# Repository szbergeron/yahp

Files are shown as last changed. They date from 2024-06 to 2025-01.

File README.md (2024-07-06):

WARN: Not ready for use yet

The boards are semi-final, but I need to finish part selection and push a new variant that allows varying sensor position.
Code is in Proof-of-Concept state, and has a lot of stuff hard-coded that should be pulled out into configs.

#Because getting an AvantGrand would just be way too easy

Inspired by [Greg Zweigle's DIY Hybrid Piano](https://github.com/gzweigle/DIY-Grand-Digital-Piano) and the [Cybrid Project](https://github.com/ekumanov/cybrid).

I don't come from a hardware/EE background, so a lot of that stuff was done by feel rather than through meticulous science. Instead, I tried to all of the "magic" through software. The sensors are probably not "ideal", but they are cheap and dumb simple. I didn't use trimmers or anything like that to calibrate, opting instead to gather raw measurements and then apply software correction. I also opted to use onboard ADCs instead of external ones or any kind of extra voltage reference. This absolutely introduces some inaccuracy in the lower bits of the raw measurements, but again--software magic :)

The flip side of using such a simple design from an EE perspective is that fabrication is _dumb simple_, even if technically more expensive when looking at the BOM. Each key uses a single sensor, and there is an MCU for every 16 keys, plus some basic power filtering all on a PCB. I'm spectacularly bad at soldering, so this has as little of it as I could get away with. This project is aimed at being an easy "kit" to get components for and assemble. Follow along if you'd like!

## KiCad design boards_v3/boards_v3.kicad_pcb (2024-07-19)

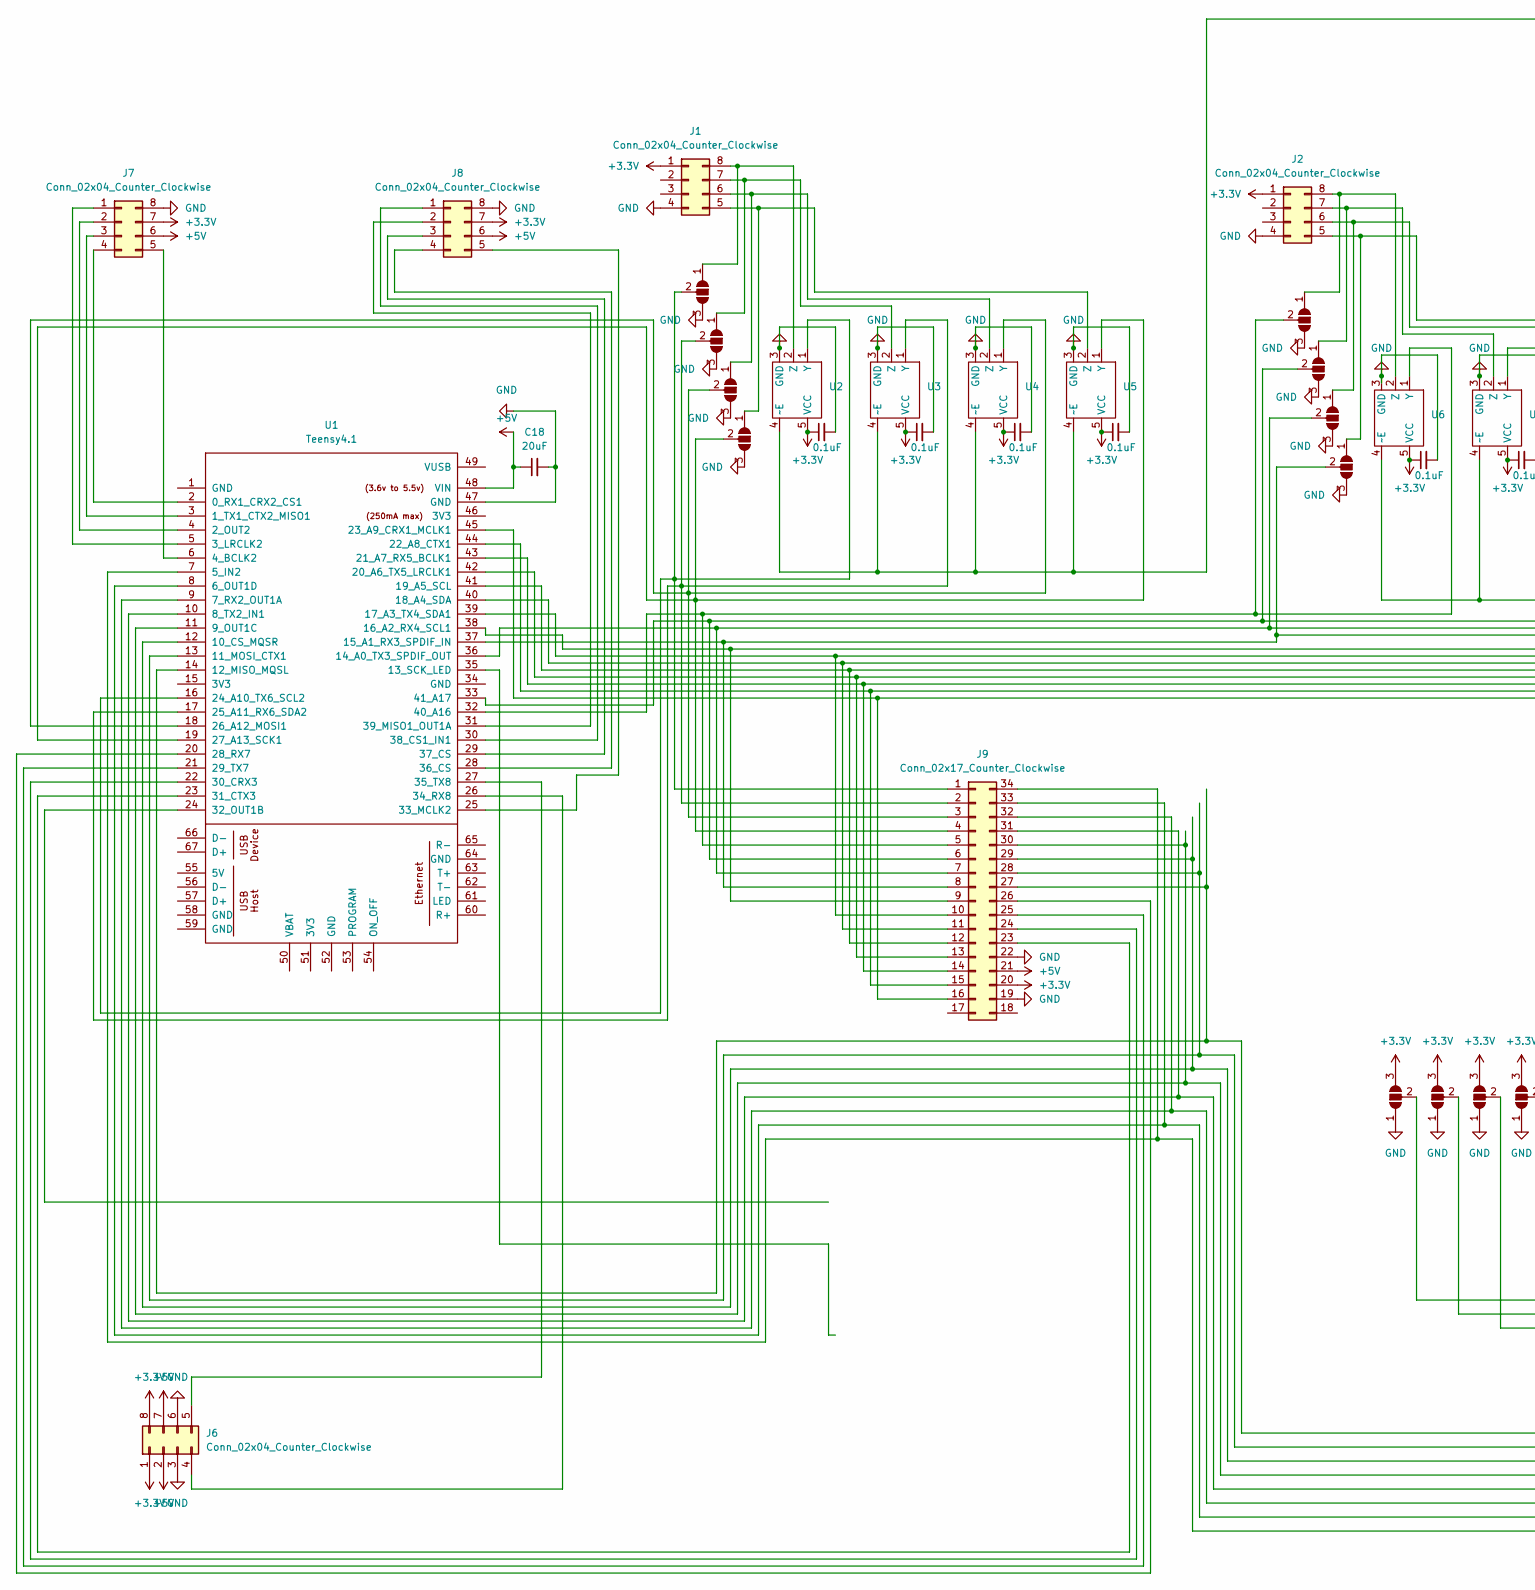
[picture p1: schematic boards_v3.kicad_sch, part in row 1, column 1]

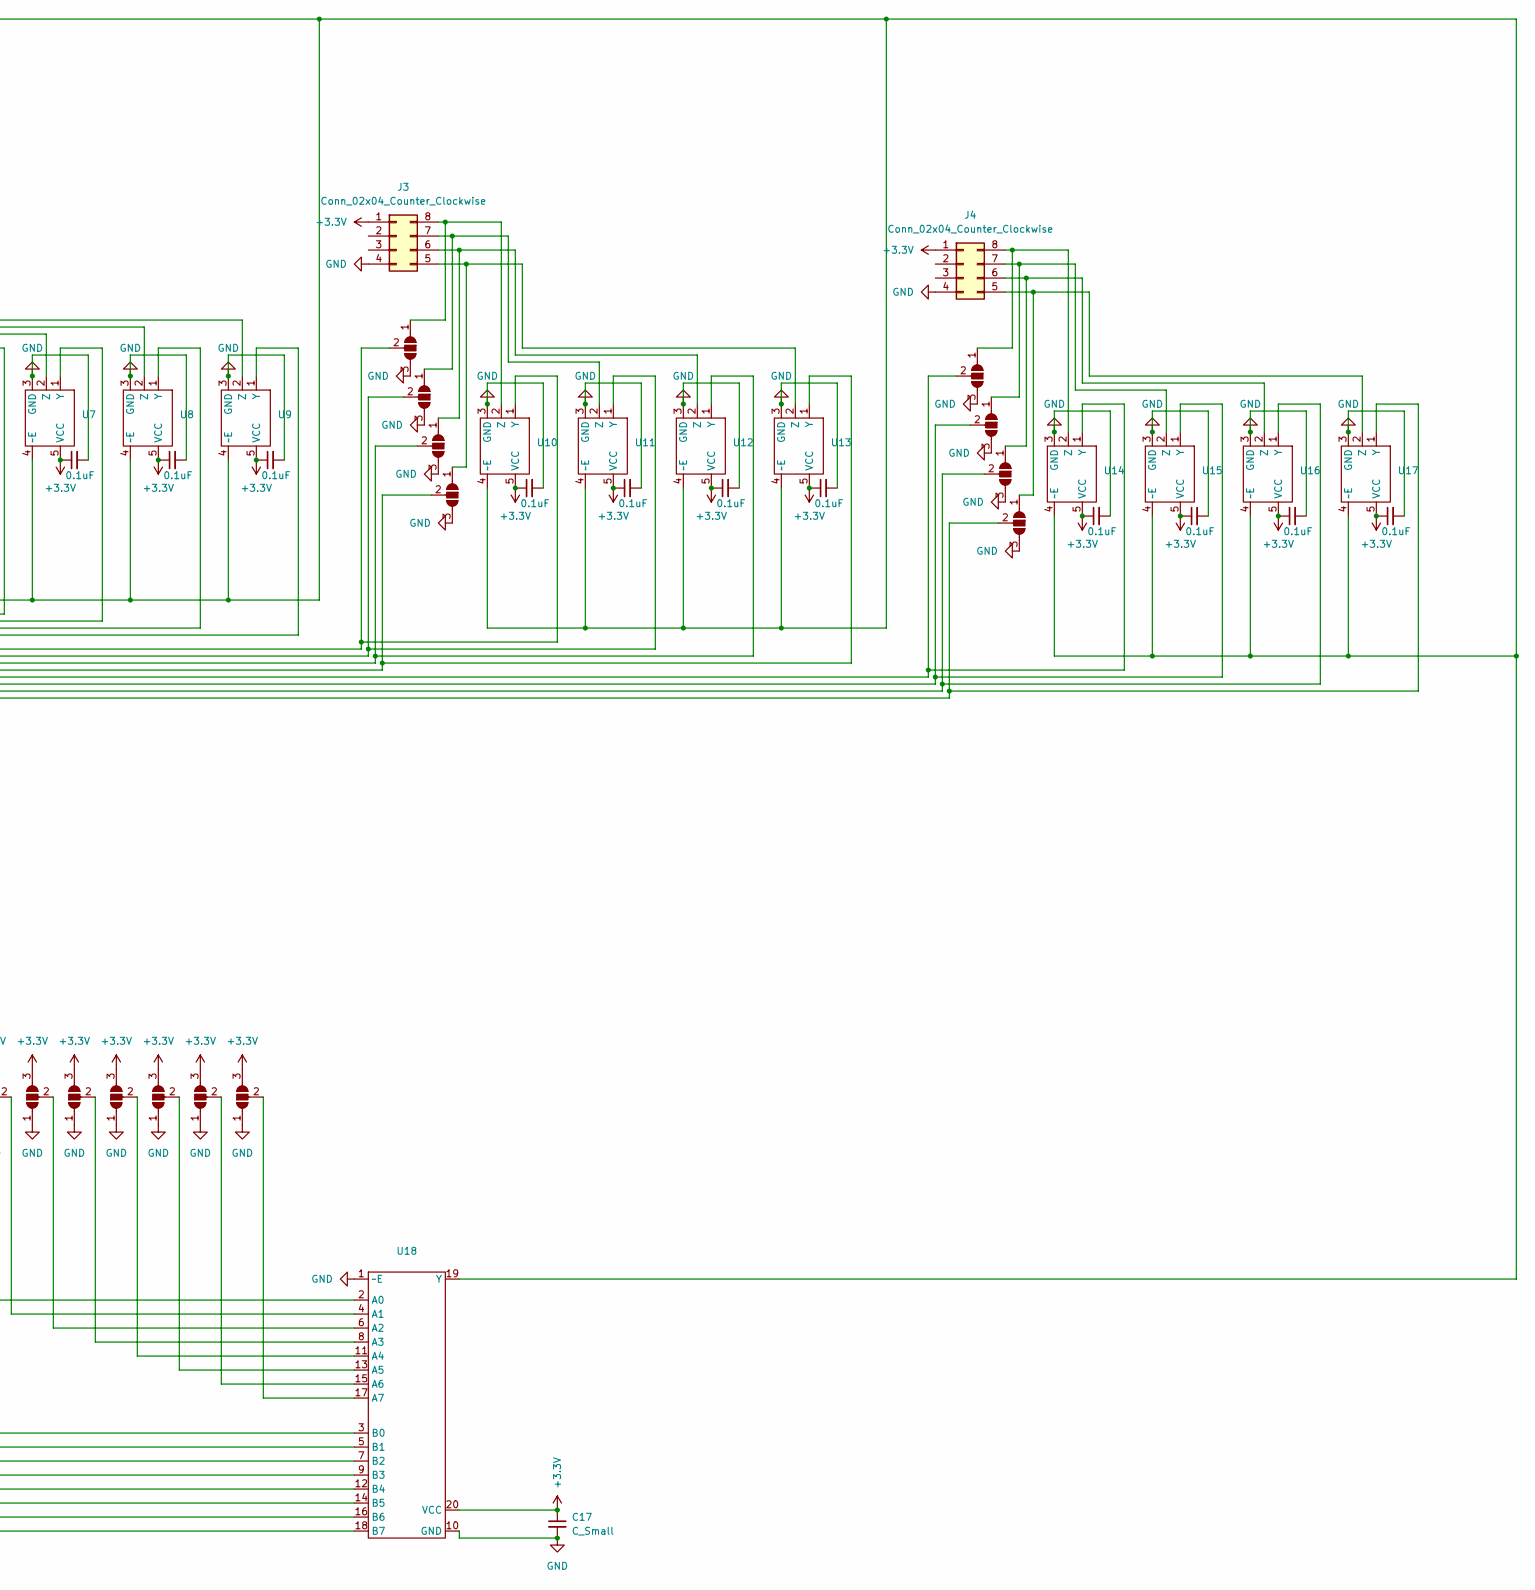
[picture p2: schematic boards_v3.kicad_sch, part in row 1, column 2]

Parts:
C1, C2, C3, C4, C5, C6, C7, C8, C9, C10, C11, C12, C13, C14, C15, C16: 0.1uF; C_1206_3216Metric_Pad1.33x1.80mm_HandSolder
C17: C_Small; C_1206_3216Metric_Pad1.33x1.80mm_HandSolder
C18: 20uF; C_1812_4532Metric_Pad1.57x3.40mm_HandSolder
J1, J2, J3, J4, J6, J7, J8: Conn_02x04_Counter_Clockwise; Conn_02x04_2.54mm_pin
J9: Conn_02x17_Counter_Clockwise; Conn_02x17_2.54mm_pin
JP1, JP2, JP3, JP4, JP5, JP6, JP7, JP8, JP9, JP10, JP11, JP12, JP13, JP14, JP15, JP16, JP17, JP18, JP19, JP20, JP21, JP22, JP23, JP24: SolderJumper_3_Open; SolderJumper-3_P1.3mm_Open_RoundedPad1.0x1.5mm
U1: Teensy4.1; Teensy41
U2, U3, U4, U5, U6, U7, U8, U9, U10, U11, U12, U13, U14, U15, U16, U17: SC-74A-5_1.55x2.9mm_P0.95mm
U18: SOIC-20W_7.5x12.8mm_P1.27mm

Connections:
+3.3V: C1.1, C2.1, C3.1, C4.1, C5.1, C6.1, C7.1, C8.1, C9.1, C10.1, C11.1, C12.1, C13.1, C14.1, C15.1, C16.1, C17.1, J1.1, J2.1, J3.1, J4.1, J6.1, J6.8, J7.7, J8.7, J9.20, JP17.3 (B), JP18.3 (B), JP19.3 (B), JP20.3 (B), JP21.3 (B), JP22.3 (B), JP23.3 (B), JP24.3 (B), U2.5 (VCC), U3.5 (VCC), U4.5 (VCC), U5.5 (VCC), U6.5 (VCC), U7.5 (VCC), U8.5 (VCC), U9.5 (VCC), U10.5 (VCC), U11.5 (VCC), U12.5 (VCC), U13.5 (VCC), U14.5 (VCC), U15.5 (VCC), U16.5 (VCC), U17.5 (VCC), U18.20 (VCC)
+5V: C18.1, J6.2, J6.7, J7.6, J8.6, J9.21, U1.48 (VIN)
GND: C1.2, C2.2, C3.2, C4.2, C5.2, C6.2, C7.2, C8.2, C9.2, C10.2, C11.2, C12.2, C13.2, C14.2, C15.2, C16.2, C17.2, C18.2, J1.4, J2.4, J3.4, J4.4, J6.3, J6.6, J7.8, J8.8, J9.19, J9.22, JP1.3 (B), JP2.3 (B), JP3.3 (B), JP4.3 (B), JP5.3 (B), JP6.3 (B), JP7.3 (B), JP8.3 (B), JP9.3 (B), JP10.3 (B), JP11.3 (B), JP12.3 (B), JP13.3 (B), JP14.3 (B), JP15.3 (B), JP16.3 (B), JP17.1 (A), JP18.1 (A), JP19.1 (A), JP20.1 (A), JP21.1 (A), JP22.1 (A), JP23.1 (A), JP24.1 (A), U1.47 (GND), U2.3 (GND), U3.3 (GND), U4.3 (GND), U5.3 (GND), U6.3 (GND), U7.3 (GND), U8.3 (GND), U9.3 (GND), U10.3 (GND), U11.3 (GND), U12.3 (GND), U13.3 (GND), U14.3 (GND), U15.3 (GND), U16.3 (GND), U17.3 (GND), U18.1 (~E), U18.10 (GND)
unnamed: J1.5, JP4.1 (A), U5.2 (Z)
unnamed: J1.6, JP3.1 (A), U4.2 (Z)
unnamed: J1.7, JP2.1 (A), U3.2 (Z)
unnamed: J1.8, JP1.1 (A), U2.2 (Z)
unnamed: J2.5, JP8.1 (A), U9.2 (Z)
unnamed: J2.6, JP7.1 (A), U8.2 (Z)
unnamed: J2.7, JP6.1 (A), U7.2 (Z)
unnamed: J2.8, JP5.1 (A), U6.2 (Z)
unnamed: J3.5, JP12.1 (A), U13.2 (Z)
unnamed: J3.6, JP11.1 (A), U12.2 (Z)
unnamed: J3.7, JP10.1 (A), U11.2 (Z)
unnamed: J3.8, JP9.1 (A), U10.2 (Z)
unnamed: J4.5, JP16.1 (A), U17.2 (Z)
unnamed: J4.6, JP15.1 (A), U16.2 (Z)
unnamed: J4.7, JP14.1 (A), U15.2 (Z)
unnamed: J4.8, JP13.1 (A), U14.2 (Z)
unnamed: J6.4, U1.26 (34_RX8)
unnamed: J6.5, U1.27 (35_TX8)
unnamed: J7.1, U1.5 (3_LRCLK2)
unnamed: J7.2, U1.4 (2_OUT2)
unnamed: J7.3, U1.3 (1_TX1_CTX2_MISO1)
unnamed: J7.4, U1.2 (0_RX1_CRX2_CS1)
unnamed: J7.5, U1.6 (4_BCLK2)
unnamed: J8.1, U1.30 (38_CS1_IN1)
unnamed: J8.2, U1.31 (39_MISO1_OUT1A)
unnamed: J8.3, U1.29 (37_CS)
unnamed: J8.4, U1.28 (36_CS)
unnamed: J8.5, U1.25 (33_MCLK2)
unnamed: J9.1, JP1.2 (C), U1.16 (24_A10_TX6_SCL2), U2.1 (Y)
unnamed: J9.2, JP2.2 (C), U1.17 (25_A11_RX6_SDA2), U3.1 (Y)
unnamed: J9.3, JP3.2 (C), U1.18 (26_A12_MOSI1), U4.1 (Y)
unnamed: J9.4, JP4.2 (C), U1.19 (27_A13_SCK1), U5.1 (Y)
unnamed: J9.5, JP5.2 (C), U1.32 (40_A16), U6.1 (Y)
unnamed: J9.6, JP6.2 (C), U1.33 (41_A17), U7.1 (Y)
unnamed: J9.7, JP7.2 (C), U1.36 (14_A0_TX3_SPDIF_OUT), U8.1 (Y)
unnamed: J9.8, JP8.2 (C), U1.37 (15_A1_RX3_SPDIF_IN), U9.1 (Y)
unnamed: J9.9, JP9.2 (C), U1.38 (16_A2_RX4_SCL1), U10.1 (Y)
unnamed: J9.10, JP10.2 (C), U1.39 (17_A3_TX4_SDA1), U11.1 (Y)
unnamed: J9.11, JP11.2 (C), U1.40 (18_A4_SDA), U12.1 (Y)
unnamed: J9.12, JP12.2 (C), U1.41 (19_A5_SCL), U13.1 (Y)
unnamed: J9.13, JP13.2 (C), U1.42 (20_A6_TX5_LRCLK1), U14.1 (Y)
unnamed: J9.14, JP14.2 (C), U1.43 (21_A7_RX5_BCLK1), U15.1 (Y)
unnamed: J9.15, JP15.2 (C), U1.44 (22_A8_CTX1), U16.1 (Y)
unnamed: J9.16, JP16.2 (C), U1.45 (23_A9_CRX1_MCLK1), U17.1 (Y)
unnamed: J9.23, U1.23 (31_CTX3)
unnamed: J9.24, U1.22 (30_CRX3)
unnamed: J9.25, U1.21 (29_TX7)
unnamed: J9.26, U1.20 (28_RX7)
unnamed: J9.27, U1.14 (12_MISO_MQSL), U18.3 (B0)
unnamed: J9.28, U1.13 (11_MOSI_CTX1), U18.5 (B1)
unnamed: J9.29, U1.12 (10_CS_MQSR), U18.7 (B2)
unnamed: J9.30, U1.11 (9_OUT1C), U18.9 (B3)
unnamed: J9.31, U1.10 (8_TX2_IN1), U18.12 (B4)
unnamed: J9.32, U1.9 (7_RX2_OUT1A), U18.14 (B5)
unnamed: J9.33, U1.8 (6_OUT1D), U18.16 (B6)
unnamed: J9.34, U1.7 (5_IN2), U18.18 (B7)
unnamed: JP17.2 (C), U18.2 (A0)
unnamed: JP18.2 (C), U18.4 (A1)
unnamed: JP19.2 (C), U18.6 (A2)
unnamed: JP20.2 (C), U18.8 (A3)
unnamed: JP21.2 (C), U18.11 (A4)
unnamed: JP22.2 (C), U18.13 (A5)
unnamed: JP23.2 (C), U18.15 (A6)
unnamed: JP24.2 (C), U18.17 (A7)
unnamed: U2.4 (~E), U3.4 (~E), U4.4 (~E), U5.4 (~E), U6.4 (~E), U7.4 (~E), U8.4 (~E), U9.4 (~E), U10.4 (~E), U11.4 (~E), U12.4 (~E), U13.4 (~E), U14.4 (~E), U15.4 (~E), U16.4 (~E), U17.4 (~E), U18.19 (Y)

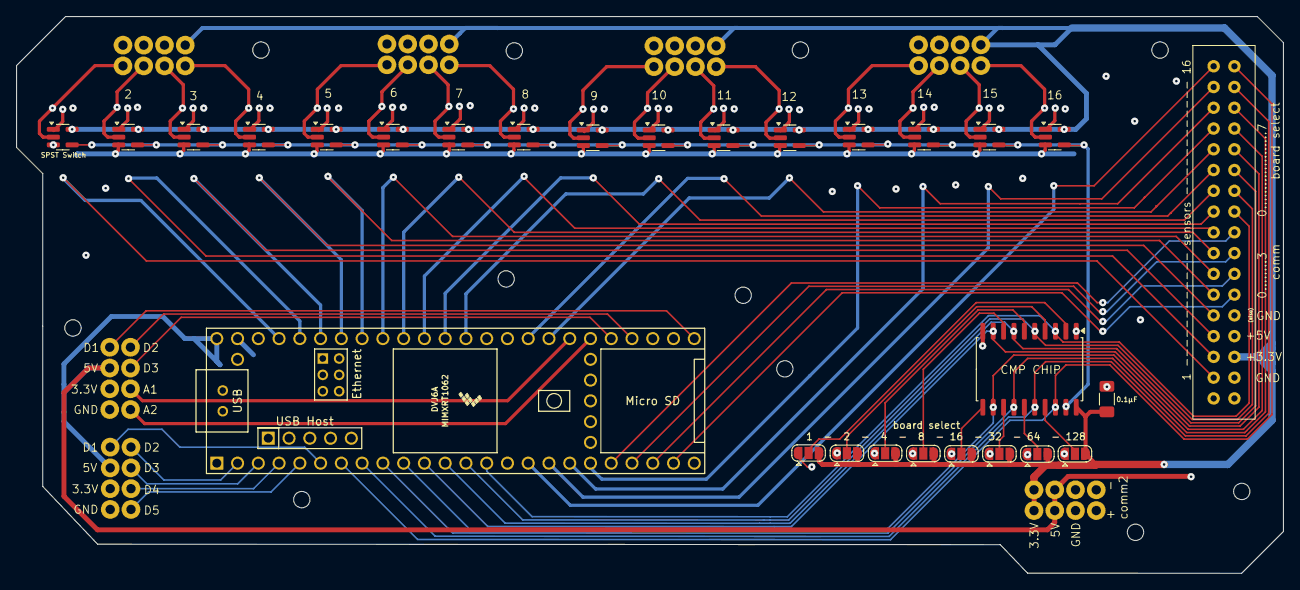
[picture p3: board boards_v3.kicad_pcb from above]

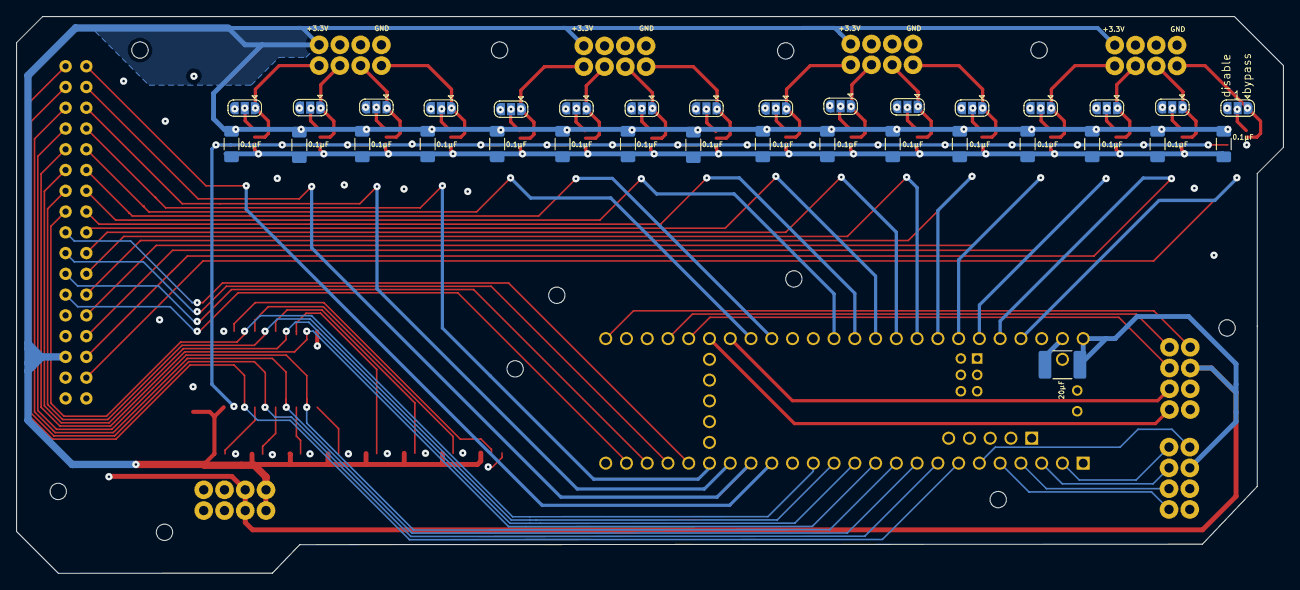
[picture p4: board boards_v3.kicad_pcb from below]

Board: 4 copper layers, 155.0 x 68.1 mm, 68 parts (33 on the bottom side), 68 nets.

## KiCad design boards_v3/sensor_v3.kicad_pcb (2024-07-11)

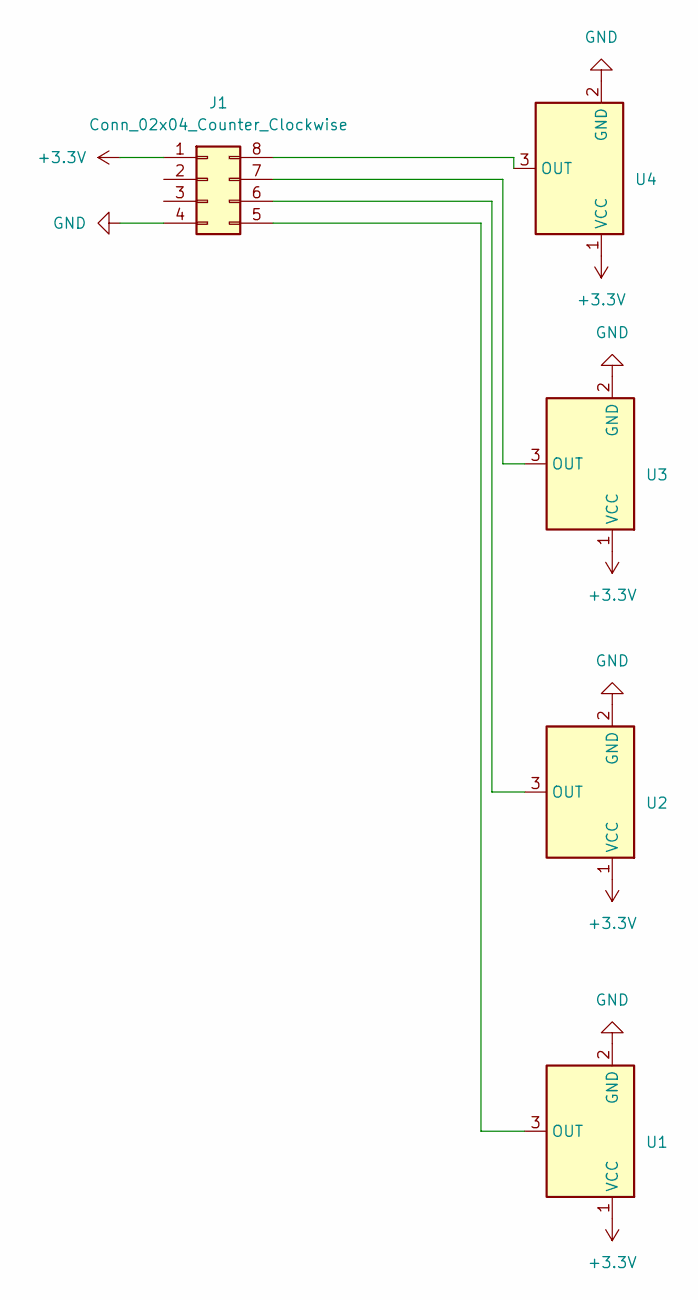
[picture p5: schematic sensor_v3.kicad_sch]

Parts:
J1: Conn_02x04_Counter_Clockwise; Conn_02x04_2.54mm_pin
U1, U2, U3, U4: DRV5055A1xLPGxQ1; TO-92_Inline_Wide

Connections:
+3.3V: J1.1, U1.1 (VCC), U2.1 (VCC), U3.1 (VCC), U4.1 (VCC)
GND: J1.4, U1.2 (GND), U2.2 (GND), U3.2 (GND), U4.2 (GND)
unnamed: J1.5, U1.3 (OUT)
unnamed: J1.6, U2.3 (OUT)
unnamed: J1.7, U3.3 (OUT)
unnamed: J1.8, U4.3 (OUT)

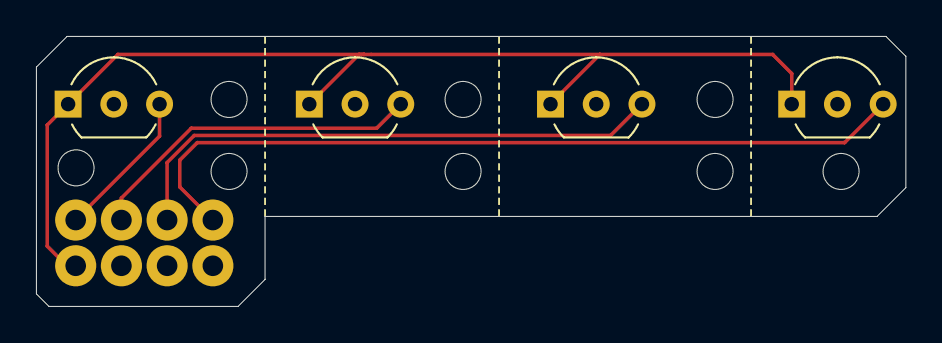
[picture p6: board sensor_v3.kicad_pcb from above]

Board: 2 copper layers, 48.3 x 15.0 mm, 5 parts (0 on the bottom side), 6 nets.

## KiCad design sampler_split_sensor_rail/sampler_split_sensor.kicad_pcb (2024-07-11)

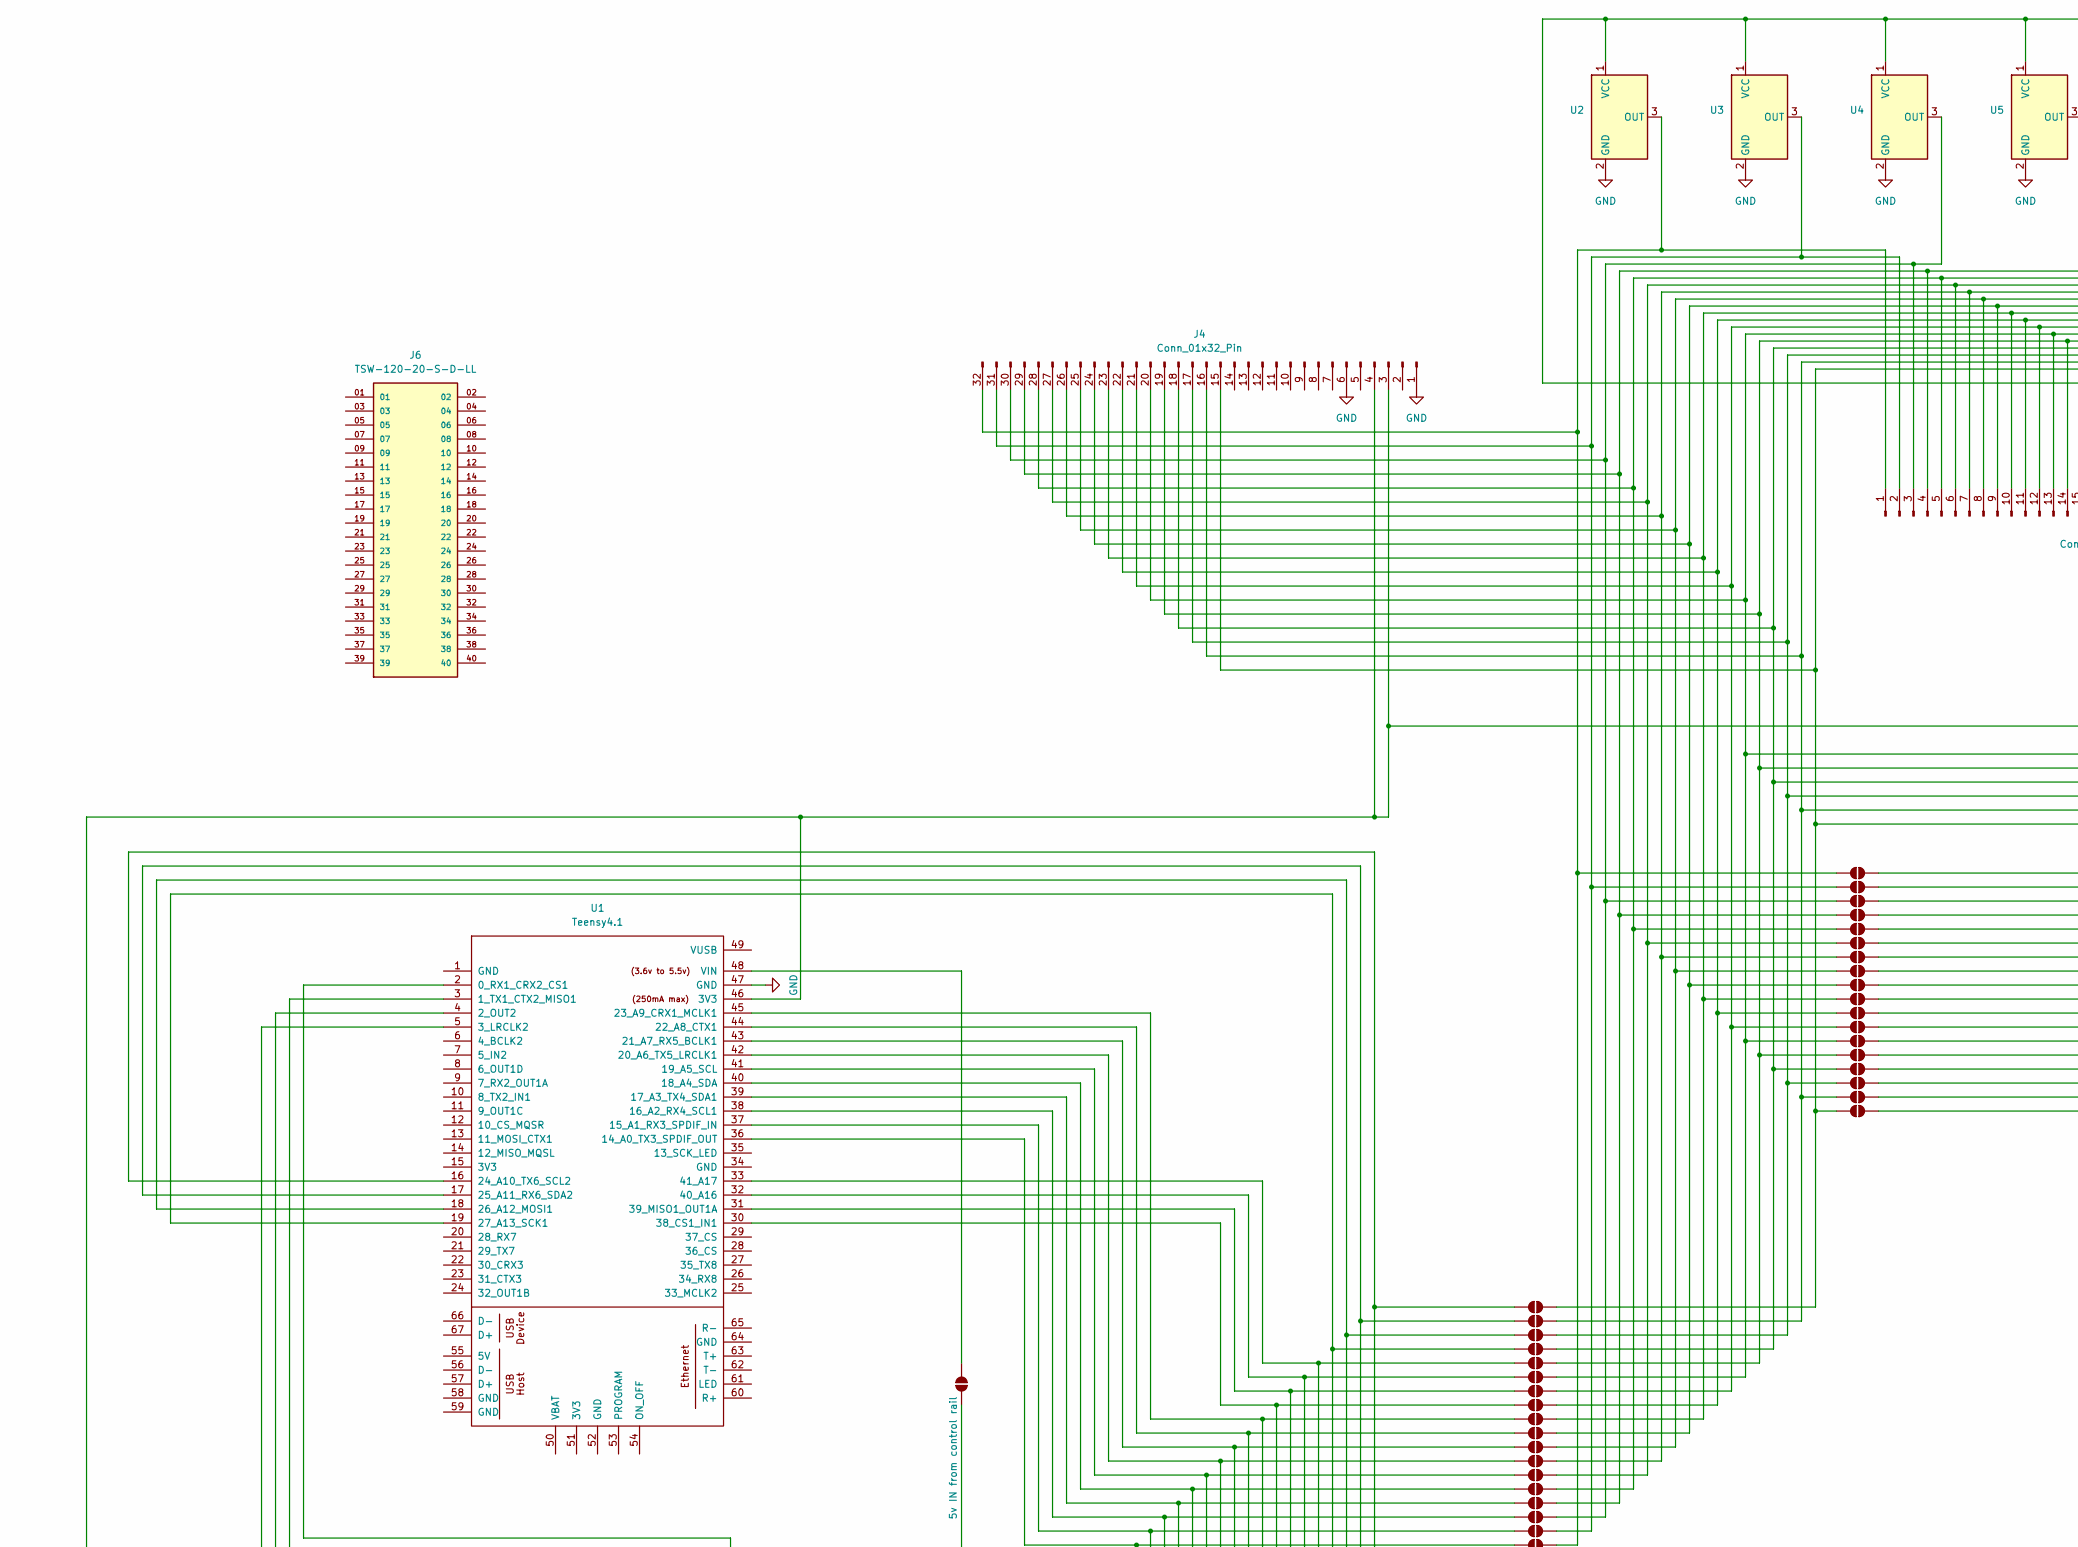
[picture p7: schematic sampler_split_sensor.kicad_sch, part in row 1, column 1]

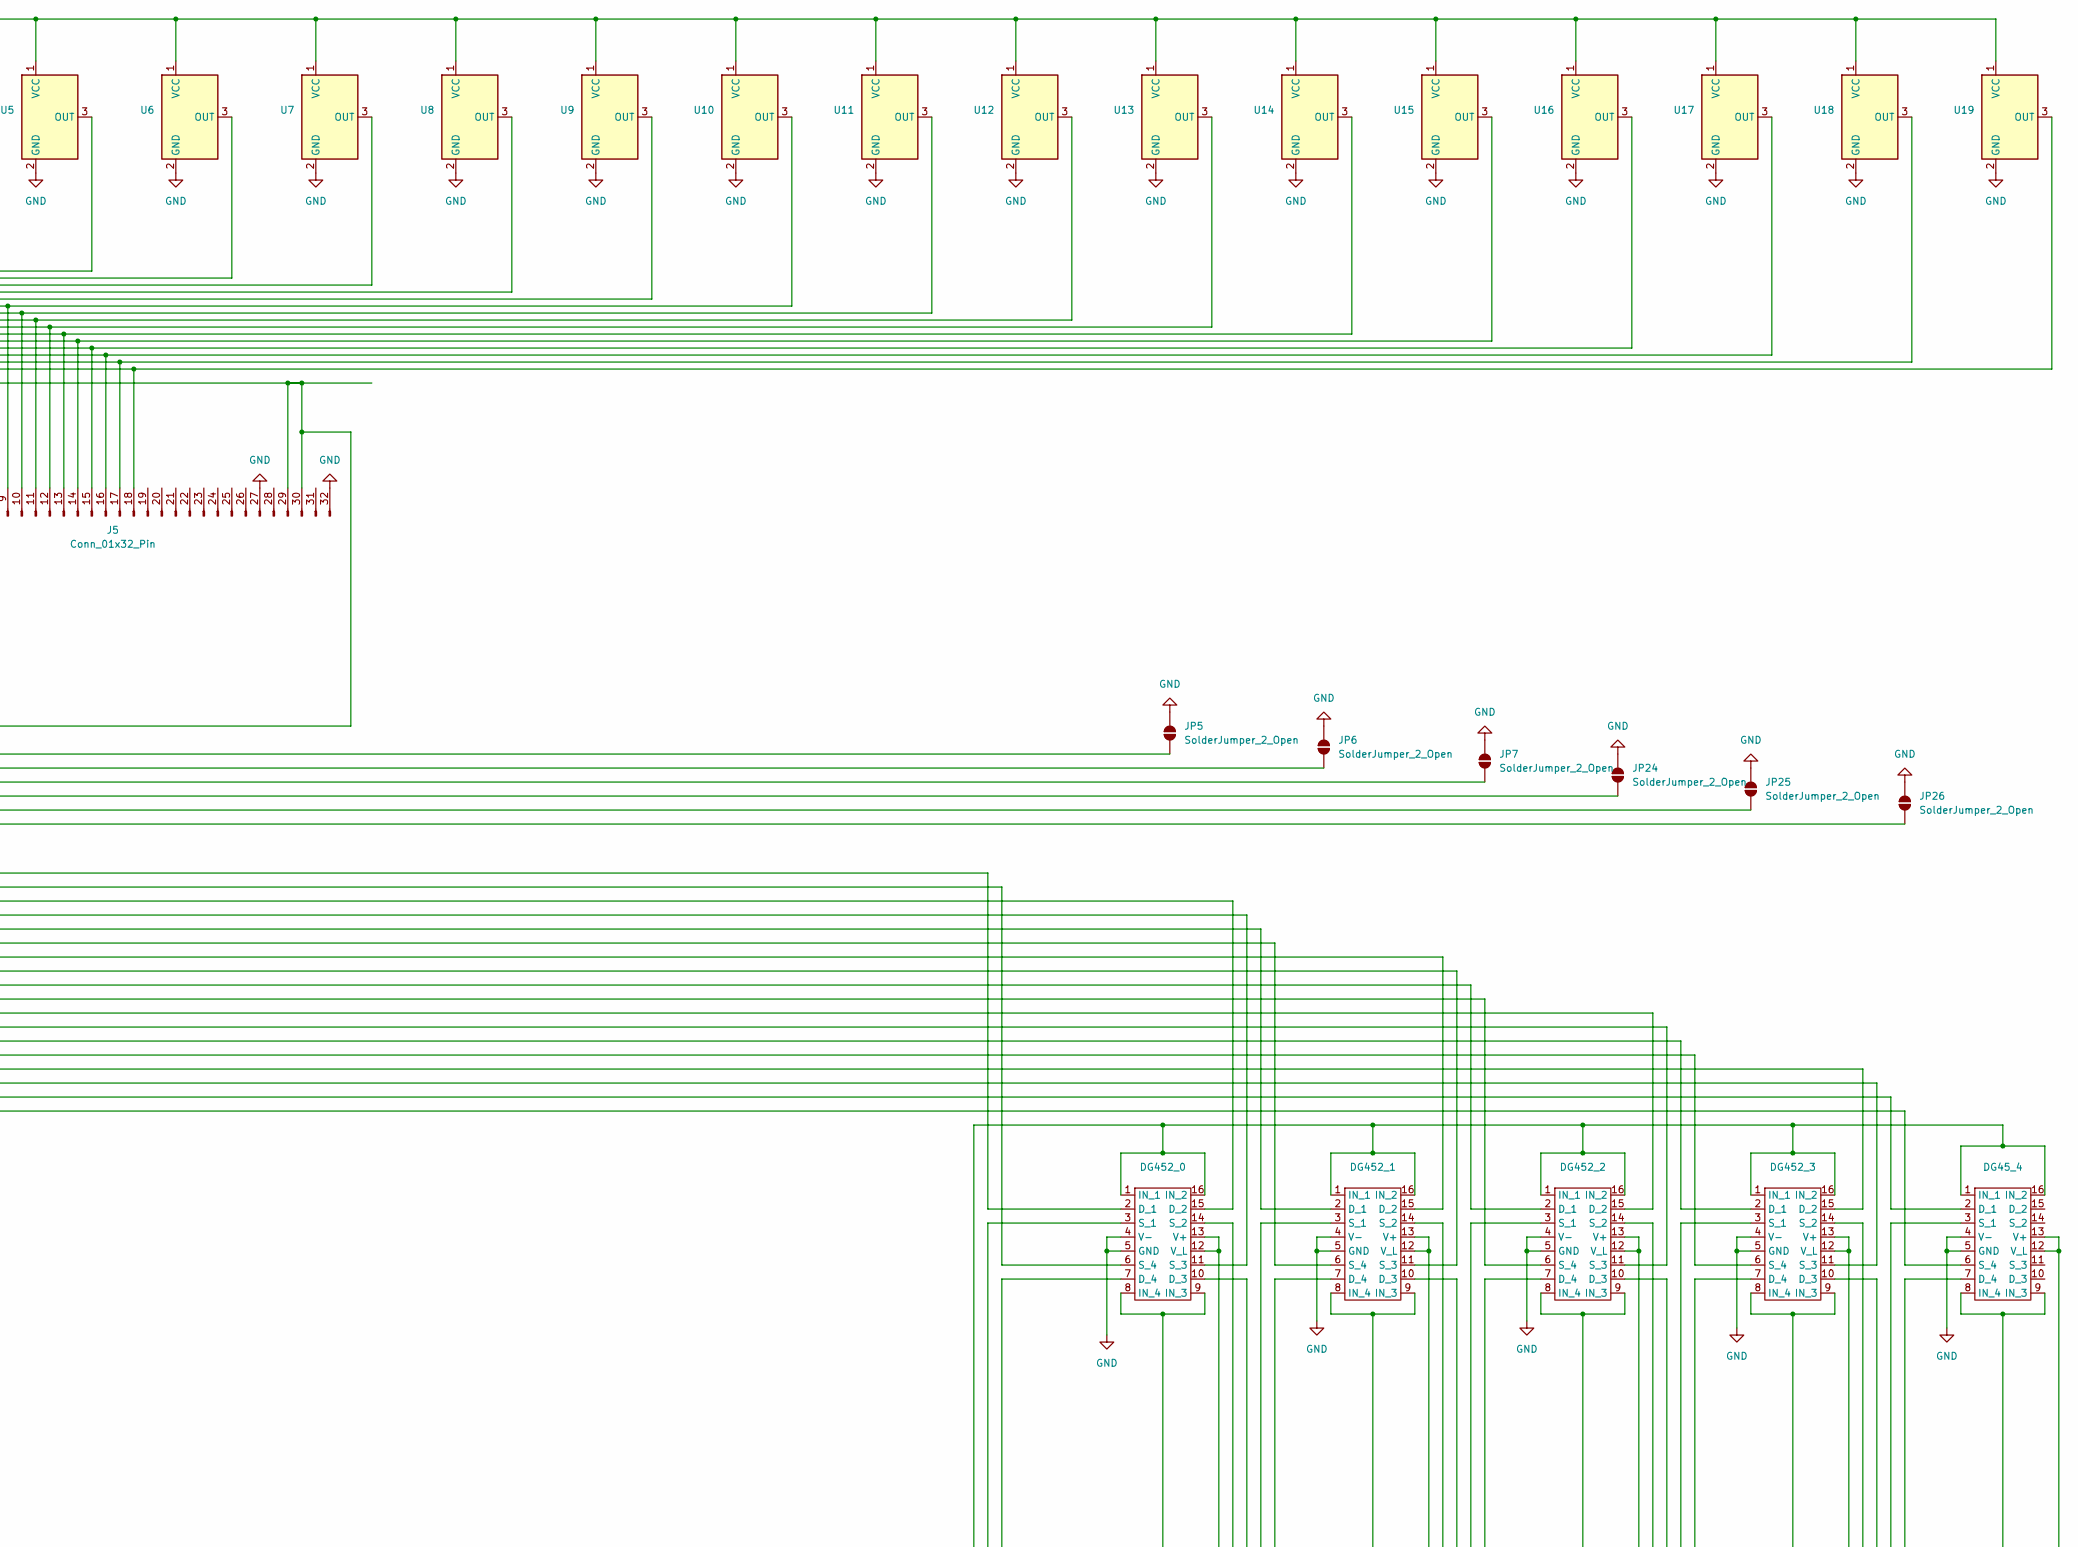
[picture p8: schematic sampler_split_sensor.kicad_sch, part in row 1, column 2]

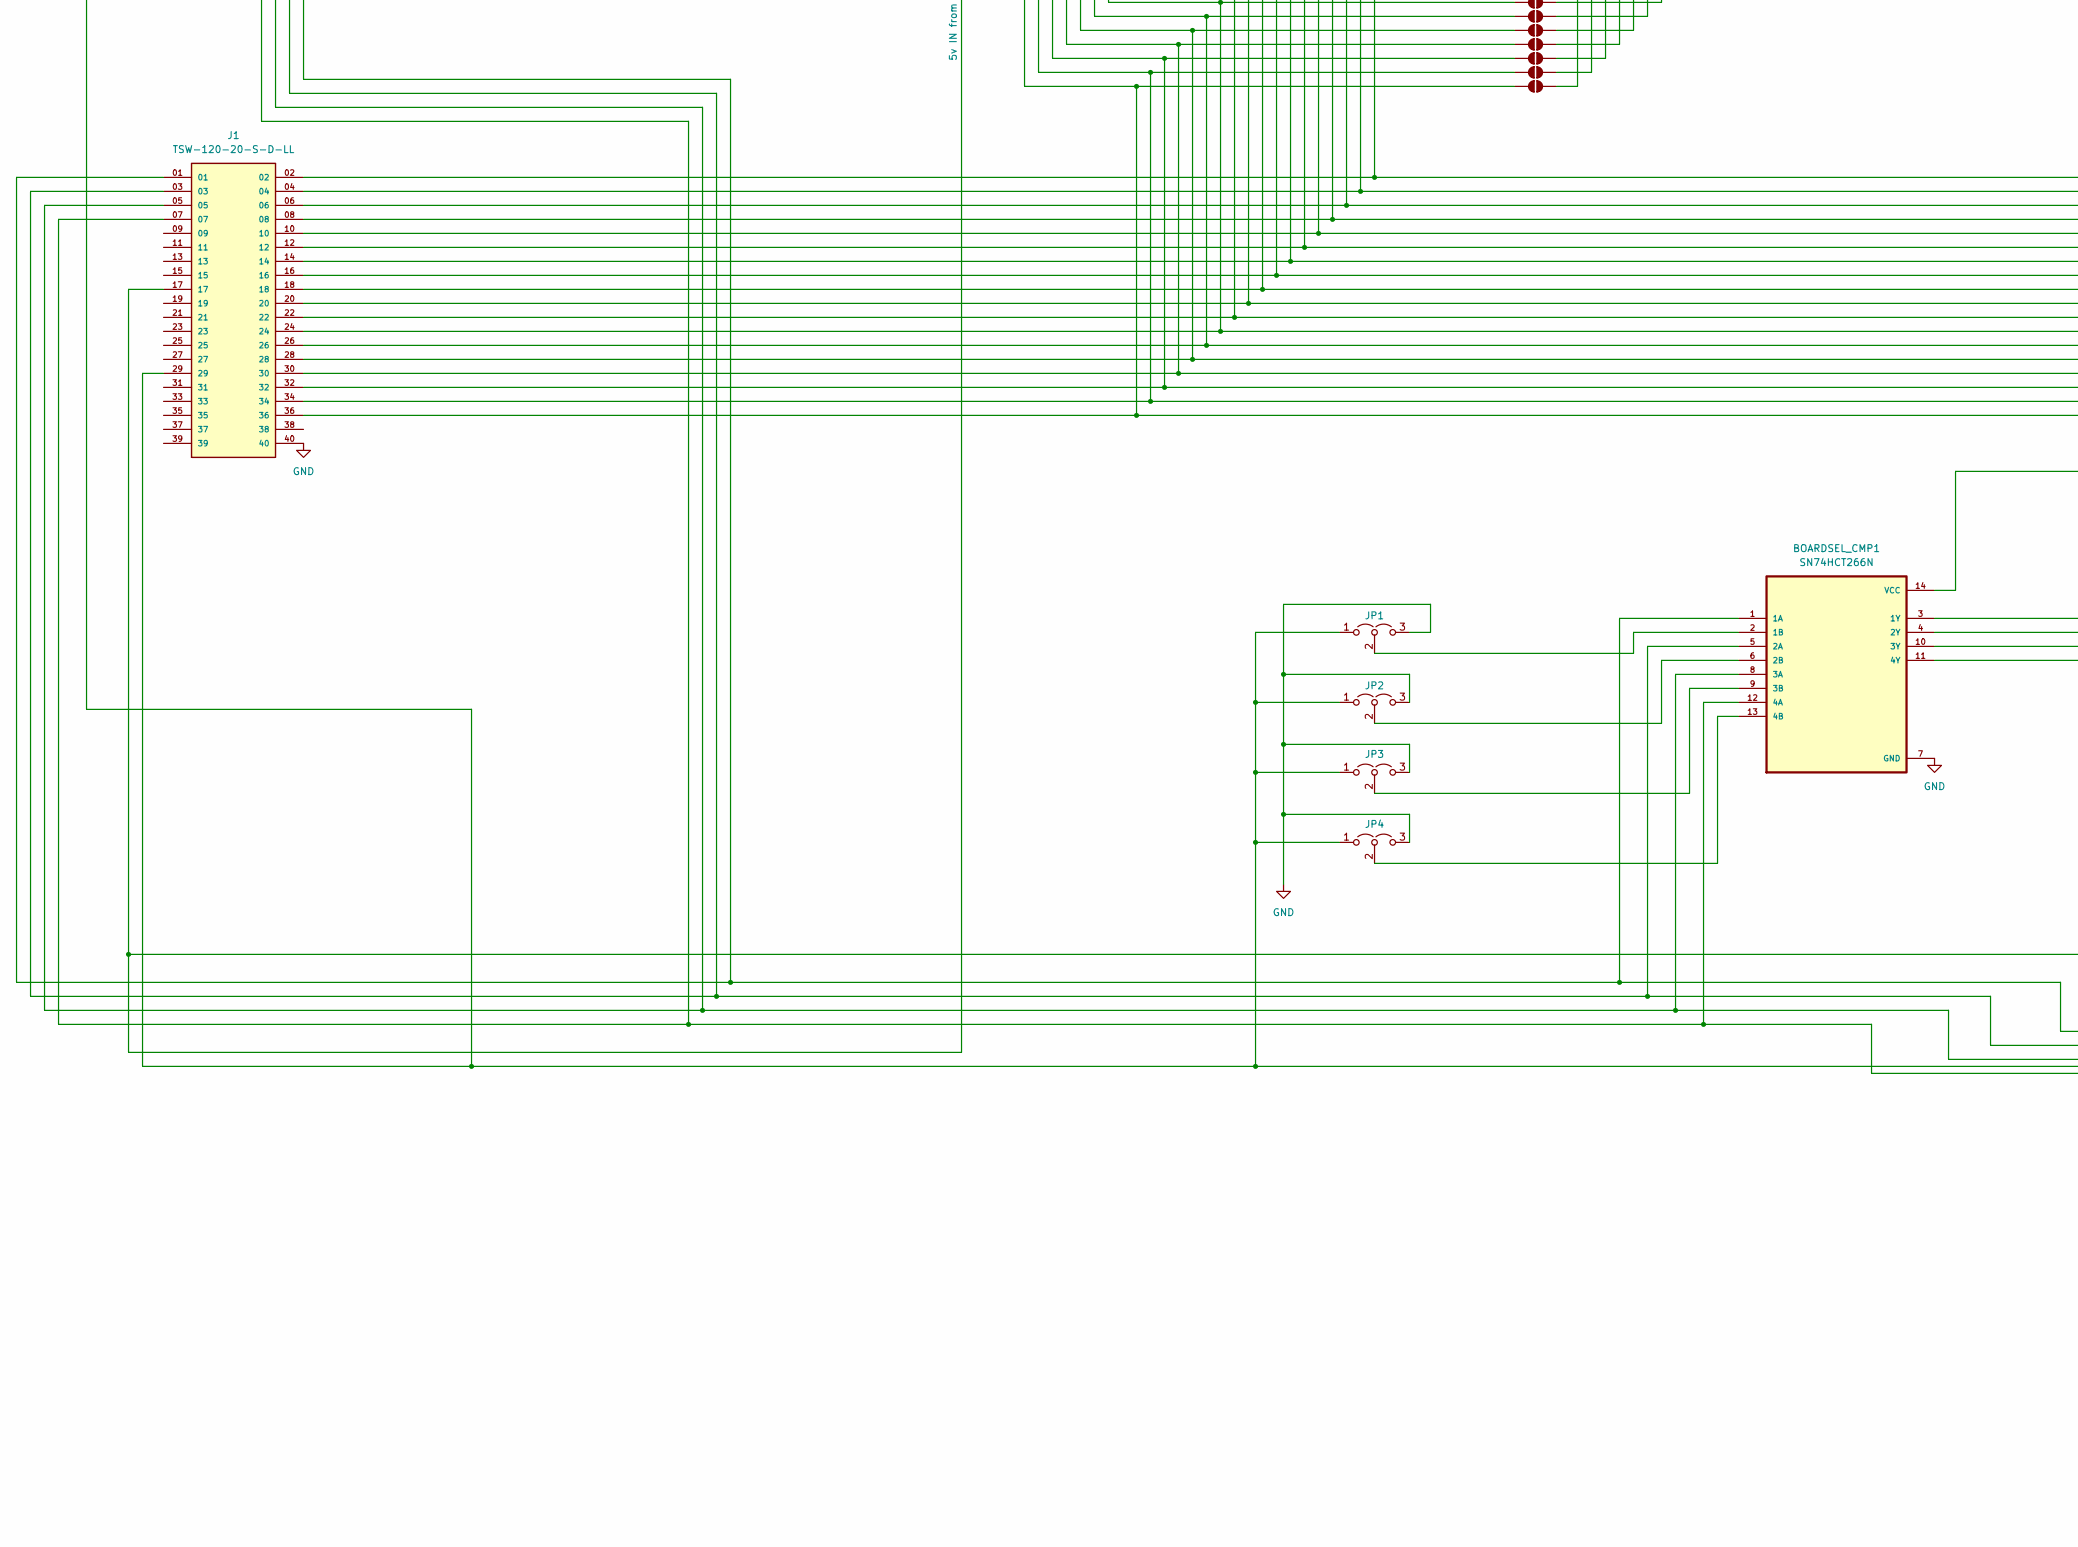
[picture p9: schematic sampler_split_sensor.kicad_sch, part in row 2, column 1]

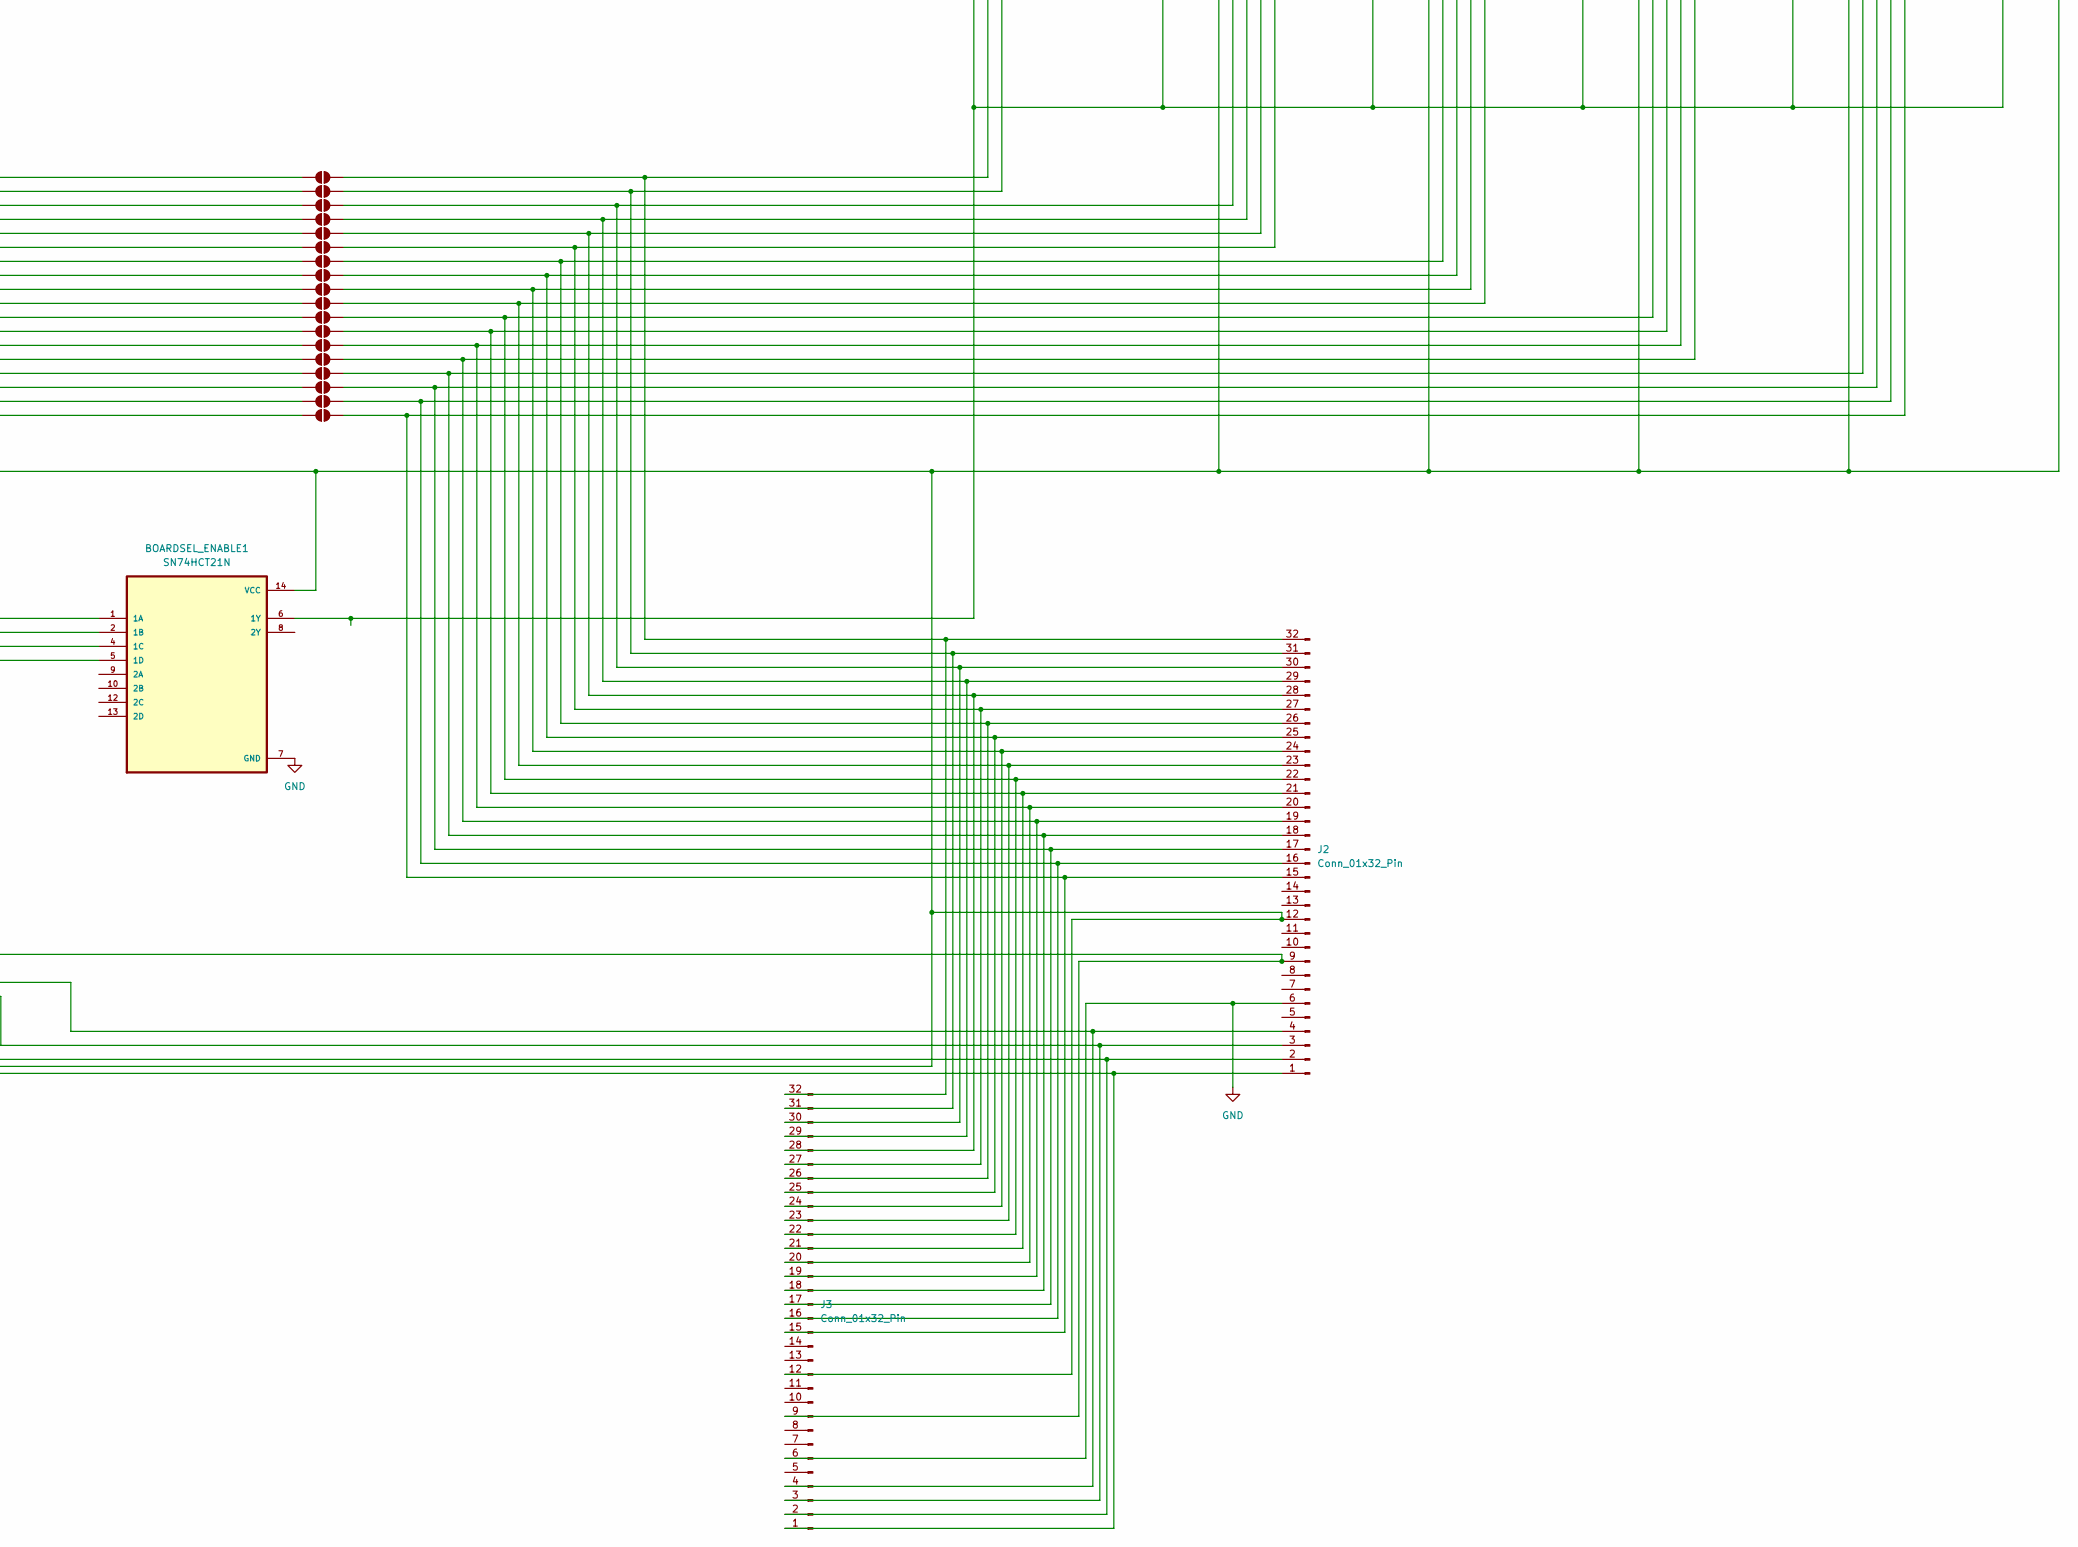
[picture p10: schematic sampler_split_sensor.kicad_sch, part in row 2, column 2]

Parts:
BOARDSEL_CMP1: SN74HCT266N; DIP794W45P254L1969H508Q14
BOARDSEL_ENABLE1: SN74HCT21N; DIP794W45P254L1969H508Q14
DG45_4, DG452_0, DG452_1, DG452_2, DG452_3: SOIC127P600X175-16N
J1, J6: TSW-120-20-S-D-LL; SAMTEC_TSW-120-20-S-D-LL; PARTREV R
J2, J3, J4, J5: Conn_01x32_Pin; Conn_1x32_SMD
JP1, JP2, JP3, JP4: Jumper_3_Open; SolderJumper-3_P2.0mm_Open_TrianglePad1.0x1.5mm
JP5, JP6, JP7, JP8, JP9, JP10, JP11, JP12, JP13, JP14, JP15, JP16, JP17, JP18, JP19, JP20, JP21, JP22, JP24, JP25, JP26, JP45, JP46, JP47, JP48, JP49, JP50, JP51, JP52, JP53, JP54, JP55, JP56, JP57, JP58, JP59, JP60, JP61, JP62, JP63, JP64, JP65: SolderJumper_2_Open; SolderJumper-2_P1.3mm_Open_TrianglePad1.0x1.5mm
JP23: 5v IN from control rail; SolderJumper-2_P1.3mm_Open_TrianglePad1.0x1.5mm
JPE01, JPE02, JPE03, JPE04, JPE05, JPE06, JPE07, JPE08, JPE09, JPE10, JPE11, JPE12, JPE13, JPE14, JPE15, JPE16, JPE17, JPE18: SolderJumper_2_Open; SolderJumper-2_P1.3mm_Open_TrianglePad1.0x1.5mm
U1: Teensy4.1; Teensy41
U2, U3: DRV5055A1xLPGxQ1; TO-92_Inline_Wide
U4, U5: DRV5055A1xLPGxQ1; TO-92_Wide
U6, U7, U8, U9, U10, U11, U12, U13, U14, U15, U16, U17, U18, U19: DRV5055A1xLPGxQ1; TO-92_Inline

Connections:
GND: BOARDSEL_CMP1.7 (GND), BOARDSEL_ENABLE1.7 (GND), DG45_4.4 (V-), DG45_4.5 (GND), DG452_0.4 (V-), DG452_0.5 (GND), DG452_1.4 (V-), DG452_1.5 (GND), DG452_2.4 (V-), DG452_2.5 (GND), DG452_3.4 (V-), DG452_3.5 (GND), J1.40, J2.6, J3.6, J4.1, J4.6, J5.27, J5.32, JP1.3 (B), JP2.3 (B), JP3.3 (B), JP4.3 (B), JP5.1 (A), JP6.1 (A), JP7.1 (A), JP24.1 (A), JP25.1 (A), JP26.1 (A), U1.47 (GND), U2.2 (GND), U3.2 (GND), U4.2 (GND), U5.2 (GND), U6.2 (GND), U7.2 (GND), U8.2 (GND), U9.2 (GND), U10.2 (GND), U11.2 (GND), U12.2 (GND), U13.2 (GND), U14.2 (GND), U15.2 (GND), U16.2 (GND), U17.2 (GND), U18.2 (GND), U19.2 (GND)
unnamed: BOARDSEL_CMP1.1 (1A), J1.01, J2.4, J3.4, U1.2 (0_RX1_CRX2_CS1)
unnamed: BOARDSEL_CMP1.2 (1B), JP1.2 (C)
unnamed: BOARDSEL_CMP1.3 (1Y), BOARDSEL_ENABLE1.1 (1A)
unnamed: BOARDSEL_CMP1.5 (2A), J1.03, J2.3, J3.3, U1.3 (1_TX1_CTX2_MISO1)
unnamed: BOARDSEL_CMP1.6 (2B), JP2.2 (C)
unnamed: BOARDSEL_CMP1.4 (2Y), BOARDSEL_ENABLE1.2 (1B)
unnamed: BOARDSEL_CMP1.8 (3A), J1.05, J2.2, J3.2, U1.4 (2_OUT2)
unnamed: BOARDSEL_CMP1.9 (3B), JP3.2 (C)
unnamed: BOARDSEL_CMP1.10 (3Y), BOARDSEL_ENABLE1.4 (1C)
unnamed: BOARDSEL_CMP1.12 (4A), J1.07, J2.1, J3.1, U1.5 (3_LRCLK2)
unnamed: BOARDSEL_CMP1.13 (4B), JP4.2 (C)
unnamed: BOARDSEL_CMP1.11 (4Y), BOARDSEL_ENABLE1.5 (1D)
unnamed: BOARDSEL_CMP1.14 (VCC), BOARDSEL_ENABLE1.14 (VCC), DG45_4.12 (V_L), DG45_4.13 (V+), DG452_0.12 (V_L), DG452_0.13 (V+), DG452_1.12 (V_L), DG452_1.13 (V+), DG452_2.12 (V_L), DG452_2.13 (V+), DG452_3.12 (V_L), DG452_3.13 (V+), J1.29, J2.12, J3.12, J4.3, J4.4, J5.29, J5.30, JP1.1 (A), JP2.1 (A), JP3.1 (A), JP4.1 (A), U1.46 (3V3), U2.1 (VCC), U3.1 (VCC), U4.1 (VCC), U5.1 (VCC), U6.1 (VCC), U7.1 (VCC), U8.1 (VCC), U9.1 (VCC), U10.1 (VCC), U11.1 (VCC), U12.1 (VCC), U13.1 (VCC), U14.1 (VCC), U15.1 (VCC), U16.1 (VCC), U17.1 (VCC), U18.1 (VCC), U19.1 (VCC)
unnamed: BOARDSEL_ENABLE1.6 (1Y), DG45_4.1 (IN_1), DG45_4.8 (IN_4), DG45_4.9 (IN_3), DG45_4.16 (IN_2), DG452_0.1 (IN_1), DG452_0.8 (IN_4), DG452_0.9 (IN_3), DG452_0.16 (IN_2), DG452_1.1 (IN_1), DG452_1.8 (IN_4), DG452_1.9 (IN_3), DG452_1.16 (IN_2), DG452_2.1 (IN_1), DG452_2.8 (IN_4), DG452_2.9 (IN_3), DG452_2.16 (IN_2), DG452_3.1 (IN_1), DG452_3.8 (IN_4), DG452_3.9 (IN_3), DG452_3.16 (IN_2)
unnamed: DG45_4.2 (D_1), JP64.2 (B)
unnamed: DG45_4.7 (D_4), J2.15, J3.15, JPE18.2 (B)
unnamed: DG45_4.3 (S_1), J2.16, J3.16, JPE17.2 (B)
unnamed: DG45_4.6 (S_4), JP65.2 (B)
unnamed: DG452_0.2 (D_1), JP48.2 (B)
unnamed: DG452_0.15 (D_2), JP50.2 (B)
unnamed: DG452_0.10 (D_3), J2.29, J3.29, JPE04.2 (B)
unnamed: DG452_0.7 (D_4), J2.31, J3.31, JPE02.2 (B)
unnamed: DG452_0.3 (S_1), J2.32, J3.32, JPE01.2 (B)
unnamed: DG452_0.14 (S_2), J2.30, J3.30, JPE03.2 (B)
unnamed: DG452_0.11 (S_3), JP51.2 (B)
unnamed: DG452_0.6 (S_4), JP49.2 (B)
unnamed: DG452_1.2 (D_1), JP52.2 (B)
unnamed: DG452_1.15 (D_2), JP54.2 (B)
unnamed: DG452_1.10 (D_3), J2.25, J3.25, JPE08.2 (B)
unnamed: DG452_1.7 (D_4), J2.27, J3.27, JPE06.2 (B)
unnamed: DG452_1.3 (S_1), J2.28, J3.28, JPE05.2 (B)
unnamed: DG452_1.14 (S_2), J2.26, J3.26, JPE07.2 (B)
unnamed: DG452_1.11 (S_3), JP55.2 (B)
unnamed: DG452_1.6 (S_4), JP53.2 (B)
unnamed: DG452_2.2 (D_1), JP56.2 (B)
unnamed: DG452_2.15 (D_2), JP58.2 (B)
unnamed: DG452_2.10 (D_3), J2.21, J3.21, JPE12.2 (B)
unnamed: DG452_2.7 (D_4), J2.23, J3.23, JPE10.2 (B)
unnamed: DG452_2.3 (S_1), J2.24, J3.24, JPE09.2 (B)
unnamed: DG452_2.14 (S_2), J2.22, J3.22, JPE11.2 (B)
unnamed: DG452_2.11 (S_3), JP59.2 (B)
unnamed: DG452_2.6 (S_4), JP57.2 (B)
unnamed: DG452_3.2 (D_1), JP60.2 (B)
unnamed: DG452_3.15 (D_2), JP62.2 (B)
unnamed: DG452_3.10 (D_3), J2.17, J3.17, JPE16.2 (B)
unnamed: DG452_3.7 (D_4), J2.19, J3.19, JPE14.2 (B)
unnamed: DG452_3.3 (S_1), J2.20, J3.20, JPE13.2 (B)
unnamed: DG452_3.14 (S_2), J2.18, J3.18, JPE15.2 (B)
unnamed: DG452_3.11 (S_3), JP63.2 (B)
unnamed: DG452_3.6 (S_4), JP61.2 (B)
unnamed: J1.17, J2.9, J3.9, JP23.1 (A)
unnamed: J4.15, J5.18, JP8.2 (B), JP26.2 (B), JP65.1 (A), U19.3 (OUT)
unnamed: J4.16, J5.17, JP9.2 (B), JP25.2 (B), JP64.1 (A), U18.3 (OUT)
unnamed: J4.17, J5.16, JP10.2 (B), JP24.2 (B), JP63.1 (A), U17.3 (OUT)
unnamed: J4.18, J5.15, JP7.2 (B), JP11.2 (B), JP62.1 (A), U16.3 (OUT)
unnamed: J4.19, J5.14, JP6.2 (B), JP12.2 (B), JP61.1 (A), U15.3 (OUT)
unnamed: J4.20, J5.13, JP5.2 (B), JP13.2 (B), JP60.1 (A), U14.3 (OUT)
unnamed: J4.21, J5.12, JP14.2 (B), JP59.1 (A), U13.3 (OUT)
unnamed: J4.22, J5.11, JP15.2 (B), JP58.1 (A), U12.3 (OUT)
unnamed: J4.23, J5.10, JP16.2 (B), JP57.1 (A), U11.3 (OUT)
unnamed: J4.24, J5.9, JP17.2 (B), JP56.1 (A), U10.3 (OUT)
unnamed: J4.25, J5.8, JP18.2 (B), JP55.1 (A), U9.3 (OUT)
unnamed: J4.26, J5.7, JP19.2 (B), JP54.1 (A), U8.3 (OUT)
unnamed: J4.27, J5.6, JP20.2 (B), JP53.1 (A), U7.3 (OUT)
unnamed: J4.28, J5.5, JP21.2 (B), JP52.1 (A), U6.3 (OUT)
unnamed: J4.29, J5.4, JP22.2 (B), JP51.1 (A), U5.3 (OUT)
unnamed: J4.30, J5.3, JP45.2 (B), JP50.1 (A), U4.3 (OUT)
unnamed: J4.31, J5.2, JP46.2 (B), JP49.1 (A), U3.3 (OUT)
unnamed: J4.32, J5.1, JP47.2 (B), JP48.1 (A), U2.3 (OUT)
unnamed: J1.02, JP8.1 (A), JPE01.1 (A), U1.16 (24_A10_TX6_SCL2)
unnamed: J1.04, JP9.1 (A), JPE02.1 (A), U1.17 (25_A11_RX6_SDA2)
unnamed: J1.06, JP10.1 (A), JPE03.1 (A), U1.18 (26_A12_MOSI1)
unnamed: J1.08, JP11.1 (A), JPE04.1 (A), U1.19 (27_A13_SCK1)
unnamed: J1.10, JP12.1 (A), JPE05.1 (A), U1.33 (41_A17)
unnamed: J1.12, JP13.1 (A), JPE06.1 (A), U1.32 (40_A16)
unnamed: J1.14, JP14.1 (A), JPE07.1 (A), U1.31 (39_MISO1_OUT1A)
unnamed: J1.16, JP15.1 (A), JPE08.1 (A), U1.30 (38_CS1_IN1)
unnamed: J1.18, JP16.1 (A), JPE09.1 (A), U1.45 (23_A9_CRX1_MCLK1)
unnamed: J1.20, JP17.1 (A), JPE10.1 (A), U1.44 (22_A8_CTX1)
unnamed: J1.22, JP18.1 (A), JPE11.1 (A), U1.43 (21_A7_RX5_BCLK1)
unnamed: J1.24, JP19.1 (A), JPE12.1 (A), U1.42 (20_A6_TX5_LRCLK1)
unnamed: J1.26, JP20.1 (A), JPE13.1 (A), U1.41 (19_A5_SCL)
unnamed: J1.28, JP21.1 (A), JPE14.1 (A), U1.40 (18_A4_SDA)
unnamed: J1.30, JP22.1 (A), JPE15.1 (A), U1.39 (17_A3_TX4_SDA1)
unnamed: JP23.2 (B), U1.48 (VIN)
unnamed: J1.32, JP45.1 (A), JPE16.1 (A), U1.38 (16_A2_RX4_SCL1)
unnamed: J1.34, JP46.1 (A), JPE17.1 (A), U1.37 (15_A1_RX3_SPDIF_IN)
unnamed: J1.36, JP47.1 (A), JPE18.1 (A), U1.36 (14_A0_TX3_SPDIF_OUT)

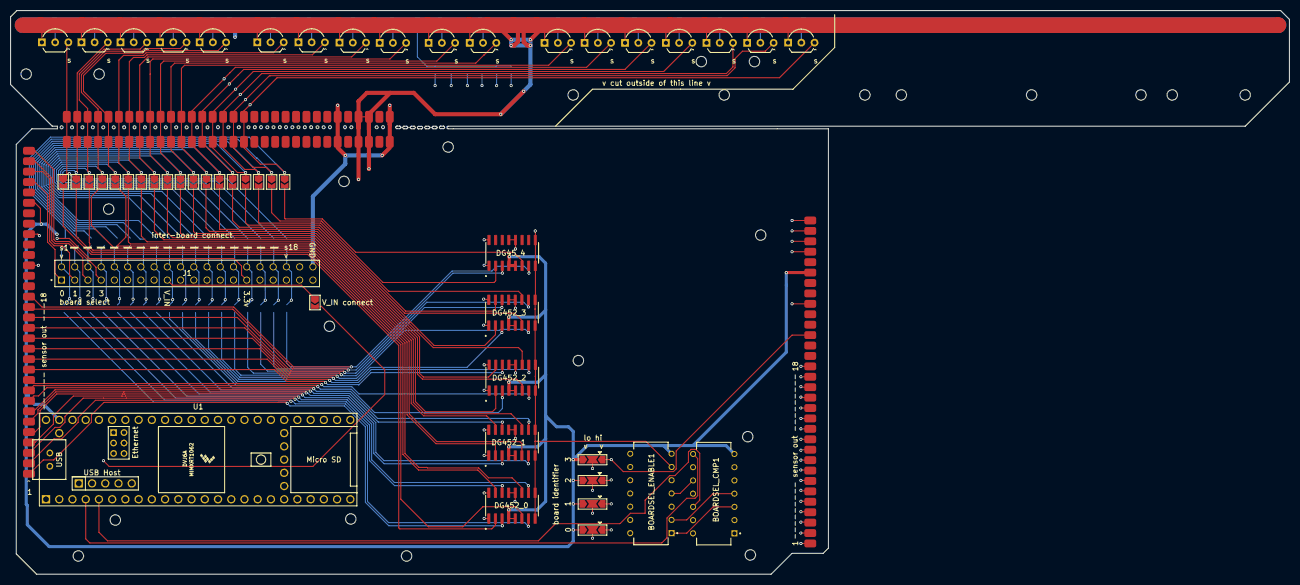
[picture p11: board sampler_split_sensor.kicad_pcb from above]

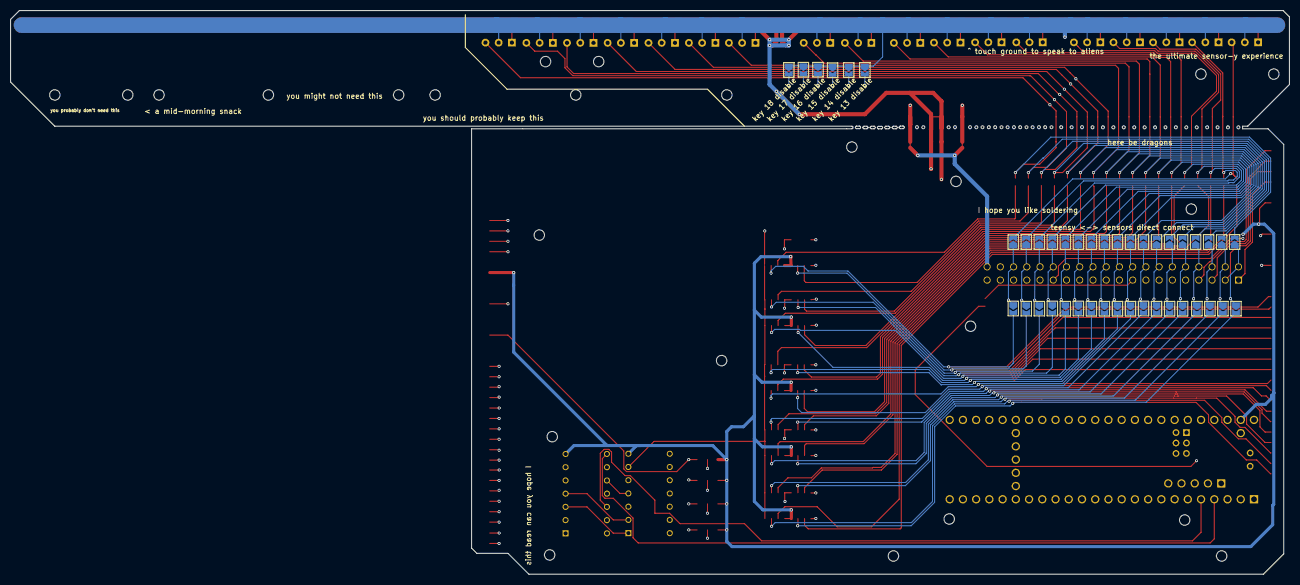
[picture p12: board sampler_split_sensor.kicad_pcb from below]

Board: 4 copper layers, 245.5 x 108.2 mm, 96 parts (42 on the bottom side), 89 nets.

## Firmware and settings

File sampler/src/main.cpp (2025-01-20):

#include "pins_arduino.h"
#define ENABLE_MIDI

#include "ADC.h"
#include "core_pins.h"
#include "usb_midi.h"
#include "utils.cpp"

#include "calibrate.cpp"
#include "keyboard.cpp"
#include "magnets.cpp"
#include "sampler2.cpp"
#include <algorithm>

// #define YAHP_DEBUG

/*struct stats_t {
  float avg_ns = 0;
  uint64_t count;

  float worst_ns = 0;

  void add_stat(uint32_t ns) {}

  bool should_run(int32_t remain_budget_ns) {
    if (remain_budget_ns > 0) {
      return true;
    }
  }

  stats_t() {}
};*/

struct idler_t {
  /*stats_t key_stats;
  stats_t pedal_stats;
  stats_t midi_stats;*/
  keyboard_t *keyboard = nullptr;

  __attribute__((always_inline)) inline void step_idle(uint32_t window_ns,
                                                       bool run_all) {
    // I know, bad, but I don't see a nanos() at the moment
    // and I'll do the translation from cycles later
    auto window = window_ns / 1000;
    auto start = micros();

    // Serial.println("Stepping idle");

    for (kbd_key_t &k : this->keyboard->keys) {
      // auto note = format_note(k.calibration.spec.midi_note);
      //  Serial.println("Processing samples for " + note);
      k.process_sample();

      if (!run_all) {
        if (micros() - start > window) {
          break;
        }
      }
    }

    /*
    for (pedal_t &p : this->keyboard->pedals) {
      p.process_sample();

      if (!run_all) {
        if (micros() - start > window) {
          break;
        }
      }
    }
    */

    if (run_all) {
      // usbMIDI.send_now();
    }
  }

  idler_t(keyboard_t *keyboard) : keyboard(keyboard) {}
};

/*char (*__kaboom)[sizeof(sampler_t)] = 1;
void kaboom_print( void )
{
    printf( "%d", __kaboom )
}*/

// static sampler_t SAMPLER;
// static keyboard_t KEYBOARD;
static uint8_t IDLER_BUF[sizeof(idler_t)];
static idler_t *IDLER = nullptr;
// union IDLER_U { uint8_t ignore, idler_t idler } IDLER;

static uint8_t SAMPLER_BUF[sizeof(sampler_t)];
static sampler_t *SAMPLER = nullptr;

static uint8_t KEYBOARD_BUF[sizeof(keyboard_t)];
static keyboard_t *KEYBOARD = nullptr;

// call this whenever there is a "pause" in sampling, or when waiting on a
// conversion, and pass the expected amount of time to idle for
//
// note, this is not a "hard" deadline: this may overrun the window.
// do not call this expecting it to return _immediately_ once the window is
// past!
//
// if run_all is set, a _full_ round will be run regardless
// of budget
//
// this is always inlined, because it is referenced in _exactly one place_,
// and I specifically want it optimized into that loop
__attribute__((always_inline)) static inline void step_idle(uint32_t window_ns,
                                                            bool run_all) {
  IDLER->step_idle(window_ns, run_all);
}

void configure_adc() {
  for (int i = 0; i < KEYS_PER_BOARD; i++) {
    auto pin = pins[i];
    pinMode(pin, INPUT_PULLDOWN);
  }

  analogReadAveraging(1);
  analogReadResolution(10);

  for (int i = 0; i < 8; i++) {
    uint8_t pin = i + 5;
    Serial.printf("Configures pin %d as output for boardsetting\r\n", pin);
    pinMode(pin, OUTPUT);
  }
}

void setup() {
  for (int i = 0; i < 5; i++) {
    delay(700);
    digitalToggle(LED_BUILTIN);
    Serial.println("Waiting...");
  }
  Serial.printf("%c\r\n", 0x07);

  configure_adc();

  Serial.println("Begin setup");

  pinMode(LED_BUILTIN, OUTPUT);

  if (!SD.begin(BUILTIN_SDCARD)) {
    Serial.println("Couldn't init SD");
    eloop("failed to setup sdcard");
  }

  Serial.println("Setting up...");
  fullspec_t spec = get_spec();

  if (newline_waiting()) {
    bool test_mode = confirm("try test mode?", false);
    if (test_mode) {
      testmode_entry();
    }

    bool do_more_calibration = confirm("recalibrate some keys?", false);
    if(do_more_calibration) {
      more_calibration(spec);
      doReboot();
    }
  }

  Serial.println("Making adc/sampler/keyboard...");
  ADC adc;

  SAMPLER = new (SAMPLER_BUF) sampler_t(adc, spec.keyboard.sampler);

  Serial.println("Made sampler");

  KEYBOARD = new (KEYBOARD_BUF) keyboard_t(spec, SAMPLER);

  IDLER = new (IDLER_BUF) idler_t(KEYBOARD);

  Serial.println("Made keyboard");

  Serial.println("Setup complete, entering loop...");

  pinMode(LED_BUILTIN, OUTPUT);

  configure_adc();

  // now, initialize all the runtime values to match CFG
  // Serial.begin(0);
  // usbMIDI.begin();
}

void poll_rarely() {
  if (newline_waiting()) {
    // enter config menu?
  }
}

uint32_t lm = 0;
bool state = false;

uint32_t lc = 0;

void loop() {
  lc++;

  if (lc % 10000 == 0) {
    poll_rarely();
  }
  // discard shit
  /*while (usbMIDI.read()) {
    // ignore incoming messages
  }*/

  auto now = millis();

  if (now - lm > 400) {
#ifdef YAHP_DEBUG
    Serial.println("looping...");
#endif
    lm = now;
    state = !state;
    digitalWrite(LED_BUILTIN, state);
  }

  // Serial.println("Reached loop");
  SAMPLER->sample_round();
  // Serial.println("Finished round");
  IDLER->step_idle(0, true);
  // Serial.println("Ended loop");
}

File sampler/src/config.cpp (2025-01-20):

// #include "ArduinoJson/Json/PrettyJsonSerializer.hpp"
#include "ArduinoJson/Object/JsonObjectConst.hpp"
#include "WProgram.h"
#include "magnets.cpp"
#include "unit.h"
#include "utils.cpp"

#include "FS.h"
#include "wiring.h"
#include <SD.h>
#include <cstddef>

using namespace ArduinoJson;

#ifndef YAHP_CONFIG
#define YAHP_CONFIG

const int KEYS_PER_BOARD = 16;
const int NUM_BOARDS = 8;
const int SAMPLE_BUFFER_LENGTH =
    16; // this should capture a dx for even the softest notes
const int SAMPLE_BATCH_TYPICAL_SIZE =
    64; // the maximum typical number of samples within a batch.
        // this can be tuned based on how many notes are
        // going to be due per batch in a reasonable worst-case
        // scenario (requiring an allocation if it exceeds this)
const uint32_t MAX_STALENESS_MICROS = 350;
const uint32_t MIN_STALENESS_MICROS = 120;
const uint32_t KEY_COUNT_MAX = 97;
const uint32_t PEDAL_COUNT_MAX = 4;
const uint32_t CONTRIB_WINDOW = 2;

const uint8_t pins[KEYS_PER_BOARD] = {A3,  A2,  A1, A0, A7,  A6,  A5,  A4,
                                      A11, A10, A9, A8, A17, A16, A13, A12};

const int PIN_COUNT = 42;

struct key_spec_t {
  uint32_t sensor_id = 0;

  float bound_min = 0.0;
  float bound_max = 1.0;

  // the value observed by the sensor when...

#ifdef USE_CONTRIB_WINDOW
  // each of these is normalized to a 0-1
  // position of both `self` and the neighboring
  // sensors
  // some non-linear factor? is it needed?
  vector_t<float, CONTRIB_WINDOW> factor_left;
  vector_t<float, CONTRIB_WINDOW> factor_right;
#endif

  uint8_t midi_channel = 1;
  uint8_t midi_note = 0;

  key_spec_t() {}

  key_spec_t(uint32_t sid, uint8_t midi_note, uint8_t midi_channel)
      : sensor_id(sid), midi_channel(midi_channel), midi_note(midi_note) {}

  key_spec_t(JsonObject j)
      : sensor_id(j["sensor_id"]),
        bound_min(j.containsKey("bound_min") ? j["bound_min"] : 0.0),
        bound_max(j.containsKey("bound_max") ? j["bound_max"] : 1.0),
        midi_channel(j.containsKey("midi_channel") ? j["midi_channel"] : 1),
        midi_note(j["midi_note"]) {}

  JsonDocument to_json() {
    JsonDocument d;

    d["sensor_id"] = this->sensor_id;
    d["midi_note"] = this->midi_note;
    d["midi_channel"] = this->midi_channel;
    d["bound_min"] = this->bound_min;
    d["bound_max"] = this->bound_max;

    return d;
  }
};

struct tempboards_t {
  vector_t<uint8_t, NUM_BOARDS> boards;

  tempboards_t(vector_t<uint8_t, NUM_BOARDS> boards) : boards(boards) {}
};

struct tempkey_t {
  uint8_t board;
  uint8_t pin;

  tempkey_t(uint8_t board, uint8_t pin) : board(board), pin(pin) {}

  bool operator==(const tempkey_t& b) {
      return this->board == b.board && this->pin == b.pin;
  }
};

struct global_key_config_t {
  // values between 0 and 1, with 1 being the max value,
  // and 0 being the min value according to the key_spec

  float active = 0.05;

  // the point where the jack moves off
  // of the knuckle and the hammer
  // begins flying freely
  float letoff = 0.75;

  // the point where the hammer
  // makes contact with the "string".
  // note that this is not the max value,
  // since the hammer can actually bounce
  // a bit below the max value when playing
  // softer than the calibration strike.
  // this aims to be where the hammer
  // first makes contact with the striker rail
  float strike = 0.85;

  // the point where the jack comes back
  // onto the knuckle, and the key can be played again
  float repetition = 0.35;

  // damper_up is the point where
  // the damper should lift off of the string
  //
  // this is separate from damper_down,
  // as there is some amount of slop in real actions
  // around the dampers _and_ this prevents
  // a storm of note_on/note_off being sent
  // because of sensor noise
  float damper_up = 0.2;
  float damper_down = 0.1;

  float max_velocity = 0.29;
  float min_velocity = 0;

  int32_t transpose = 12;

  // just...flat?
  float bezier_p1x = 0;
  float bezier_p1y = 0;
  float bezier_p2x = 0.82;
  float bezier_p2y = 0.526;
  float bezier_p3x = 0.728;
  float bezier_p3y = 1.137;
  float bezier_p4x = 1;
  float bezier_p4y = 1;

  global_key_config_t() {}

  global_key_config_t(JsonObject j)
      : active(j["active"]), letoff(j["letoff"]), strike(j["strike"]),
        repetition(j["repetition"]), damper_up(j["damper_up"]),
        damper_down(j["damper_down"]), max_velocity(j["max_velocity"]),
        min_velocity(j["min_velocity"]), transpose(j["transpose"]) {
            if(!j.containsKey("transpose")) {
                Serial.println("Didn't contain transpose val!");
            }

            if(!j.containsKey("active")) {
                Serial.println("Also didn't contain active!");
            }
        }

  JsonDocument to_json() {
    JsonDocument d;
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

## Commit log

2024-06-13 Calibration tweaks
2024-06-18 add schematics, some updates to deal with key attention
    [sensor_bar_unified_muxing_1.kicad_pcb, sensor_bar_unified_muxing_1.kicad_sch]
2024-06-20 design PCB
    [sensor_bar_unified_muxing_1.kicad_pcb, sensor_bar_unified_muxing_1.kicad_sch]
2024-06-21 add split sensor board for breakaway
    [sampler_split_sensor.kicad_pcb, sampler_split_sensor.kicad_sch, sensor_bar_unified_muxing_1.kicad_pcb]
2024-07-06 Boards v3
    [boards_v3-B_Cu.gbr, boards_v3-B_Mask.gbr, boards_v3-B_Paste.gbr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]
2024-07-20 I'm so f*cking tired rn this might as well be drunk code
2024-07-22 idk adc stuff or something
2024-07-25 something is horribly broken?
    [config.cpp, key.cpp, main.cpp]
2024-07-25 idk wtf is wrong with this
    [calibrate.cpp, config.cpp, key.cpp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]
2024-07-29 a whole lot of calibration stuff ig
2024-08-01 why don't multiple board work???
2024-08-13 Mostly works for calibration,
    but going to save off and redo a bunch of the calibration flow
    to induce fewer measurement errors and allow better flexibility in the
    face of "screwing it up" on a fastcal run
    [calibrate.cpp, key.cpp, magnets.cpp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]
2025-01-20 start on new arch: rust on pi, flatbuffers for transit, teensy as smart adc, and dioxus for ui
